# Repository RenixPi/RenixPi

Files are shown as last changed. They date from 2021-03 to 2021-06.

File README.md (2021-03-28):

# Getting Started

> TODO
> Create an `.img` that be used to create SD Card with the [RaspberryPi Imager](https://www.raspberrypi.org/software/).

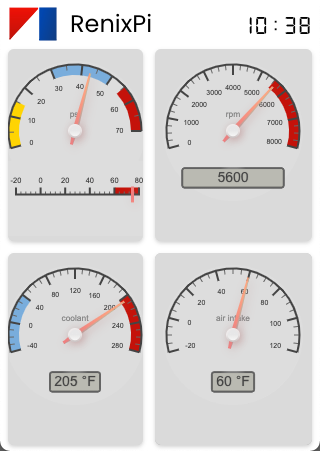
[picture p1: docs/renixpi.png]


# Renix History

A declining economy coupled with the soaring energy prices of the 1970s, American Motor Corporation (AMC)
struggled in 1980. Their vehicle lineup wasn't able to keep pace with General Motors, Chrysler and Ford. And
Japanese imports were now being produced domestically in highly efficient assembly plants.

Not able to secure loans from traditional sources, Renault provided funding to keep AMC going and eventually
acquired more than 50% of the company by 1982. The company turned focus to its Jeep brand with down-sized versions
of other models; the Wagoneer and Cherokee -- launched in 1983 -- created an entirely new sports utility vehicle
class of cars.  

Initially, these vehicles had a 2.5L inline-4 AMC engine or a GM-made 2.8L V6, both naturally aspirated with
a carburetor. In 1987, Jeep and Renault designed an inline, 6-cylinder engine. Drawing from another Renault joint
venture with aerospace company Bendix, they outfitted both the 2.5L and 4L engine with an electronic fuel injection
system. Renault-Bendix was shortened to Renix.

When Chysler acquired Jeep in 1991, they replaced the engine management system with their own ECU. However, 
during just those four years of production, Jeep sold a combined *1.1 million* Wagoneers, 
Cherokees (XJ) and Comanches (MJ) with the Renix system.

## Engine management protocols

While the On Board Diagnostic (OBD) protocol was established by [SAE in 1979](https://www.sae.org/standards/content/j1979_201202/),
it wasn't until 1994, when California emissions regulations mandated it be included on all vehicles, that it became the
industry standard now known as OBD-II.

Between 1979 and 1994, most companies used some portion of the OBD standard. Renix did not, charting their
own path with a proprietary format.

## Reverse engineering of the Renix protocol

While some commercially available diagnostic tools were made for mechanics, the protocol was never published. In 2012, a video by
[Phil Andrews of the RenixPower forum](https://www.youtube.com/watch?v=AUqQrLLVdZ8) demonstrated his hard work in decoding the protocol.

Following that, [Nick Grisley of NickInTimeDesign](http://nickintimedesign.com) started developing the
[Renix Engine Monitor](https://nickintimedesign.com/product/renix-engine-monitor-ii/) in 2016 and has been generous to
share the source code as an open source project. There are several videos on his website that show the extensive sleuthing
that was needed to arrive in his latest iteration. I've purchased one and I've been very impressed, it works great!

This project is an extension of both Phil and Nick's *tremendous* efforts and would not have been possible without them.

### Sources

- [Automotive History Preservation Society](http://wildaboutcarsonline.com/cgi-bin/pub9990262549620.cgi?itemid=9990287331811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)
- [Renix Wikipedia](https://en.wikipedia.org/wiki/Renix)
- [OBD Wikipedia](https://en.wikipedia.org/wiki/On-board_diagnostics)
- [Origins by NickInTimeDesign](https://nickintimedesign.com/where-it-all-began/)

# Electronics

The ECU serial data connection is a fairly standard interface (open-collector to ground)
which isn't dependent on the voltage of the connected electronics. Parts that are needed

- raspberry pi ~$35
- display (minimum 480x320 resolution) ~$20
- transistor (eg 2N2309) < $1
- resistors (eg 4 x 1K ohm) < $1
- power supply (see notes)  ~$4
- diagnostic connector ~$5
- wire

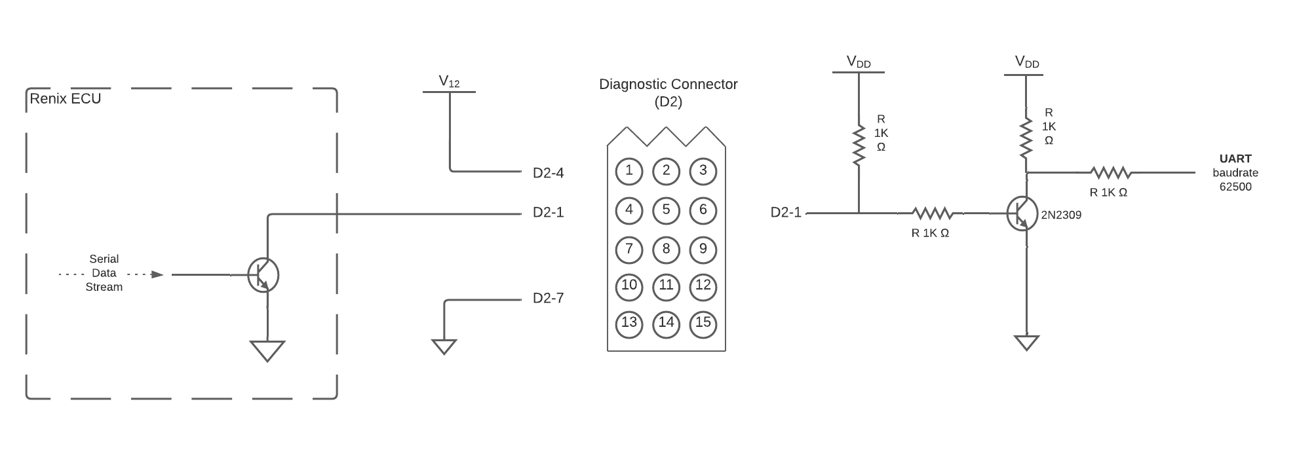
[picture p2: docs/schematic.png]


## ECU Diagnostic Connector

The diagnostic connector in the vehicle is a standard 15-pin Molex connector; receptacle with female 0.093" pins. To connect, you'll
need the [plug](<docs/molex-plug.jpeg>) (top right) with [male pins](<docs/molex-pin.jpeg>) (bottom left).

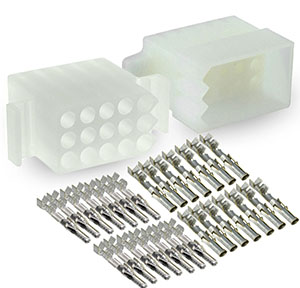
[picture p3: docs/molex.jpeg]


## Power supply

The RaspberryPi requires a 5V supply but its input pins are limited to 3.3V so the UART connection
needs this lower Vdd pull-up voltage.

**Option 1** Use Vdd from the power pins of the Raspberry Pi and level shift
the UART using a zener diode (1N4619) and a 100 ohm resistor.

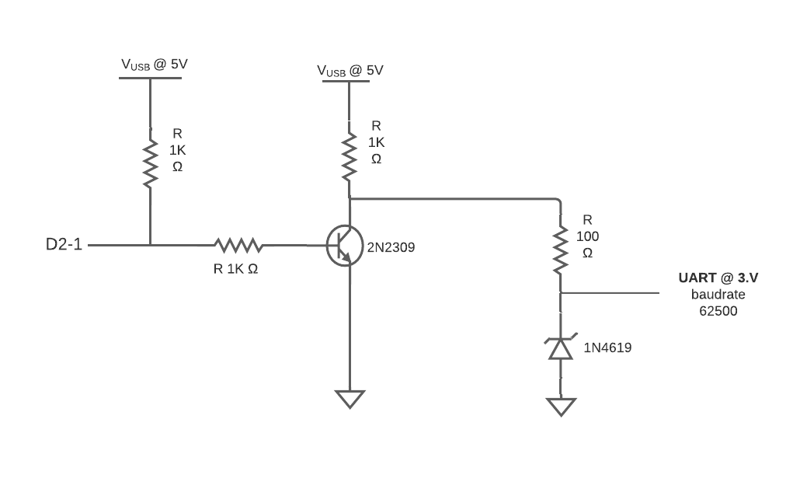
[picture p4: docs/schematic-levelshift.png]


**Option 2** Amazon or Ebay (among others) have dc-to-dc step down converters based on the
LM2596 and cost about $12 for a pack of 6. One should be adjusted to 5V and the other
to 3.3V.

**Option 3** The RaspberryPi can be powered by a USB charging port (5V) from a cigarette lighter
adapter supplying at least 2A. While the 3.3V regulator on the RaspberryPi isn't easily accessible
through the GPIO header, it might be possible to get the right voltage by configuring an output pin
and setting it to '1'. The max current is only 17 mA but, in theory, that should be enough
to activate the 2N2309 transistor.

# Software

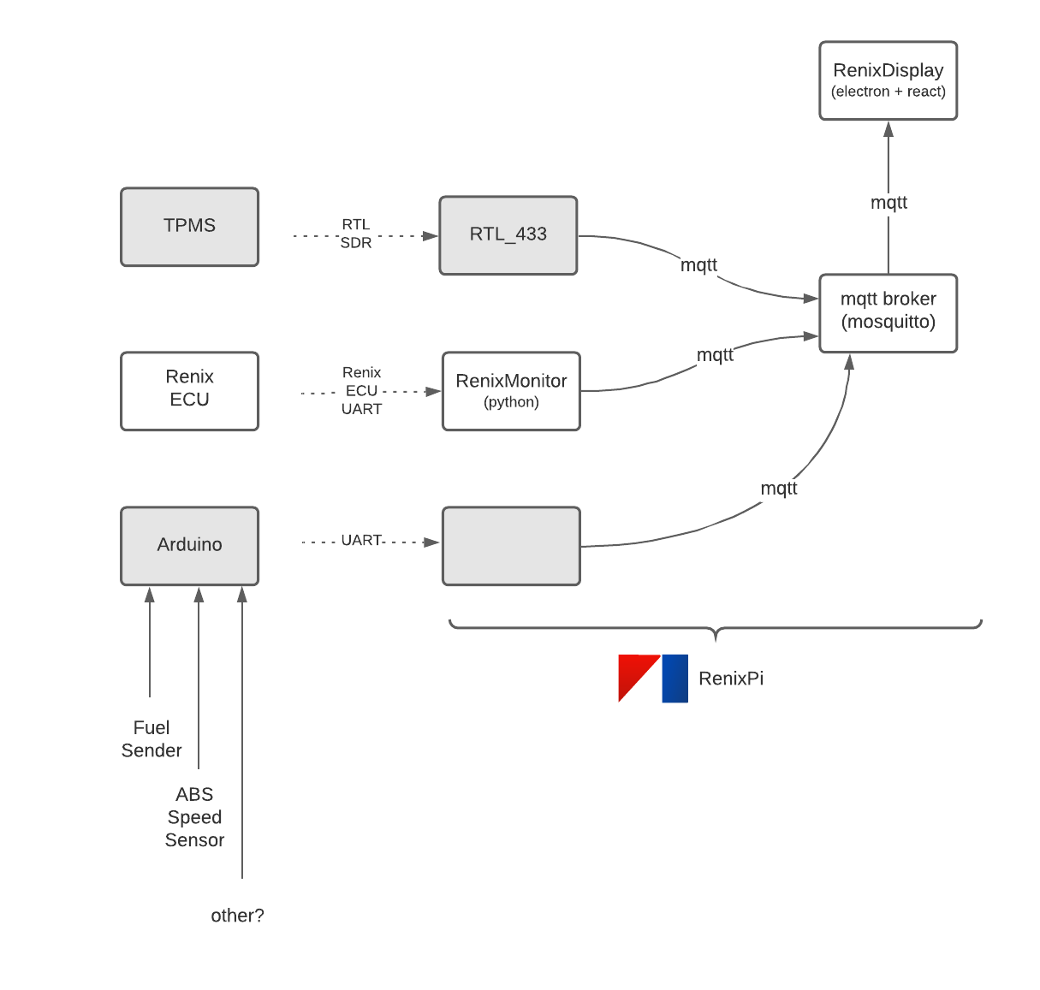
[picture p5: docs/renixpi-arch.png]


## Install

Assumes that you are using a RaspberryPI Desktop OS image that already has `git` and `python3` installed. From either a 
terminal window or command prompt via ssh:

1. clone [RenixPi](https://github.com/RenixPi/RenixPi.git)
1. install `ansible` with `pip3 install ansible`
1. `cd RenixPi/config` and run `ansible-playbook renix.yml` which will clone 
   [RenixMonitor](https://github.com/RenixPi/RenixMonitor.git) and [RenixDisplay](https://github.com/RenixPi/RenixDisplay.git)
   along with installing their dependencies.
1. `cd RenixMonitor`
1. `python3 main.py --baudrate 62500 --interface /dev/ttyAMA1 &`
1. `cd ../RenixDisplay`
1. `npm run prod` (or `npm run build` followed by `npm run launch`)

Note: on the RaspberryPi 4, there are more than two uarts so you may need to adjust the interface depending on your configuration. 

## RenixMonitor

Decodes serial data stream from Renix ECU. Python. Supports both python3 and micropython.

https://github.com/RenixPi/RenixMonitor

## RenixDisplay

Electron app built with React, Redux and RxJS. Javascript. Displays information coming from RenixMonitor and any other
MQTT source.

https://github.com/RenixPi/RenixDisplay

# Configuration

### Ethernet

No configuration necessary.

### Wireless

In the base directory of the SD card, rename `wpa_supplicant.txt` to `wpa_supplicant.conf` and change the SSID and wifi password.

### SSH

> TODO

`ssh pi@renix.local`

### Display

- size
- orientation

> TODO

### Engine Type

Currently, only 4L M/T is supported.

*Like to see this implemented? Request with a github issue!*

> TODO

#### UART

> TODO

#### TPMS (optional)

> TODO

#### Other (optional)

> TODO

# References

```
>>> # create virtual serial port
>>> socat -d -d pty,raw,echo=0 pty,raw,echo=0
```

```
>>> # run ansible to set up user and ssh config
>>> ansible-playbook -i hosts raspi.yml
```

```
>>> # run ansible to set up renix dependencies
>>> ansible-playbook -i hosts renix.yml
```

```
>>> # run electron app on raspberry pi
>>> export DISPLAY=:0
>>> npm run prod
```

```
>> # rotate screen
>> DISPLAY=:0 xrandr --output HDMI-1 --rotate left
```

```
>> # turn on display that's sleeping
>> DISPLAY=:0 xset s on s 60
>> DISPLAY=:0 xset s activate

```

references: 
https://reelyactive.github.io/diy/pi-kiosk/

## Renix Protocol

The UART-based serial protocol used by the Renix

| Byte # | 4L value | 2.5L value |
| --- | --- | --- |
| \-2 | 0xFF | 0xFF |
| \-1 | 0x00 | 0x00 |
| 0 | software version | |
| 1 | prom | |
| 2 | status | |
| 3 | mass absolute pressure | |
| 4 | coolant temp sensor | |
| 5 | intake air temp | |
| 6 | battery voltage | |
| 7 | O2 sensor | |
| 8 | spark timing (lower byte) | |
| 9 | spark timing (upper byte) | |
| 10 | injector short | |
| 11 | injector open | |
| 12 | throttle position sensor  | |
| 13 | spark advance | |
| 14 | idle air control | |
| 15 | | |
| 16 | atmospheric pressure | |
| 17 | | |
| 18 | | |
| 19 | injector pulse | |
| 20 | | |
| 21 | | |
| 22 | | |
| 23 | | |
| 24 | short fuel | |
| 25 | | |
| 26 | long fuel | |
| 27 | knock | |
| 28 | | |
| 29 | | |
| 30 | error codes | |

## A/T Transmission Protocol

*Like to see this implemented? Request with a github issue!*

## ABS Protocol

*Like to see this implemented? Request with a github issue!*

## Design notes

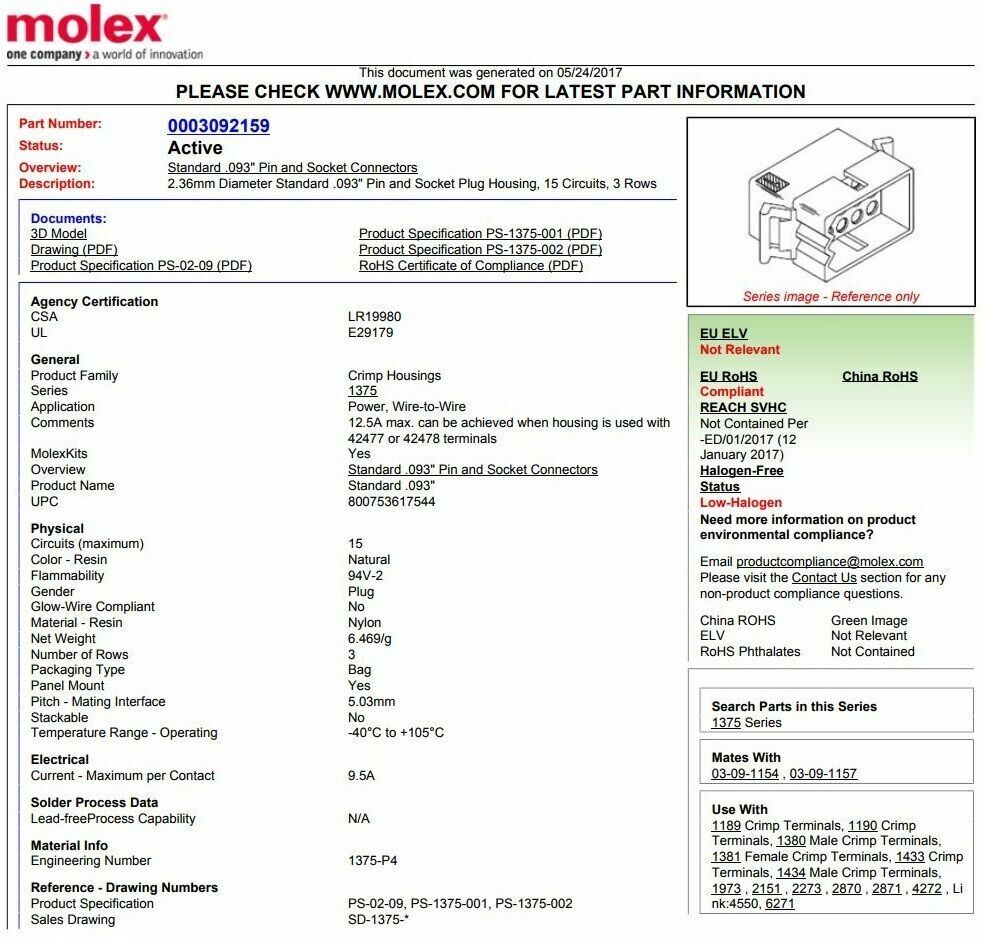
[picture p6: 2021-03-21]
docs/molex-plug.jpeg

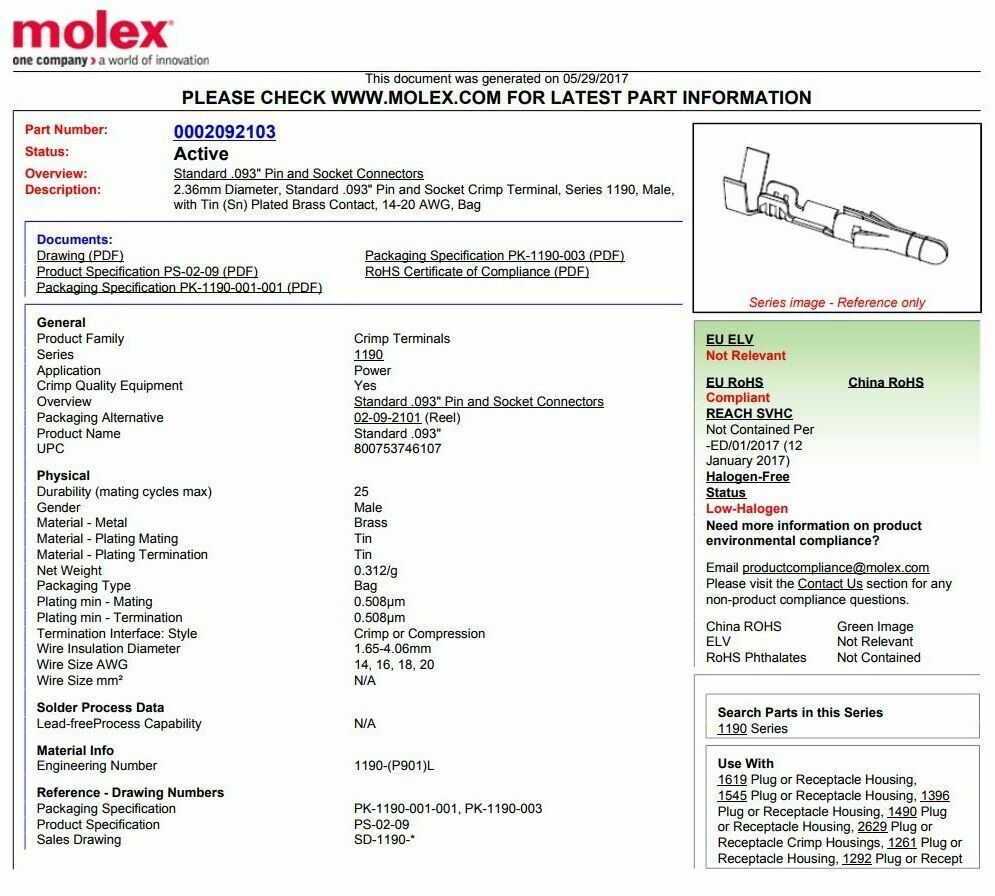
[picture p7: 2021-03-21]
docs/molex-pin.jpeg

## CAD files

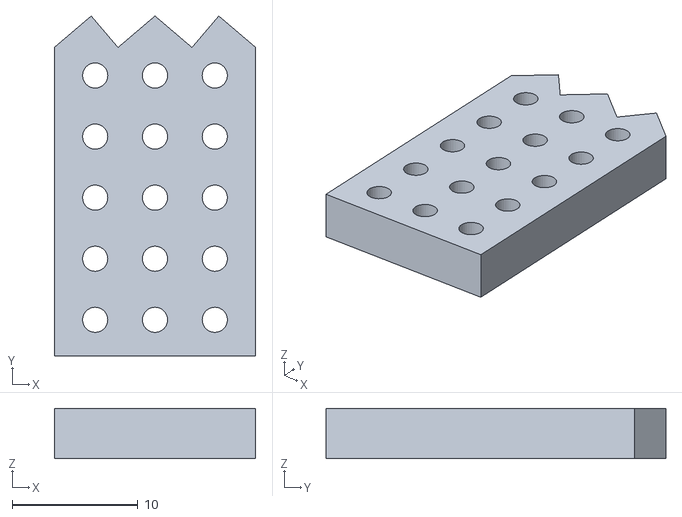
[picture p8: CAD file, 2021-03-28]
connector/renix-plug.stl
16.0 x 27.0 x 4.00

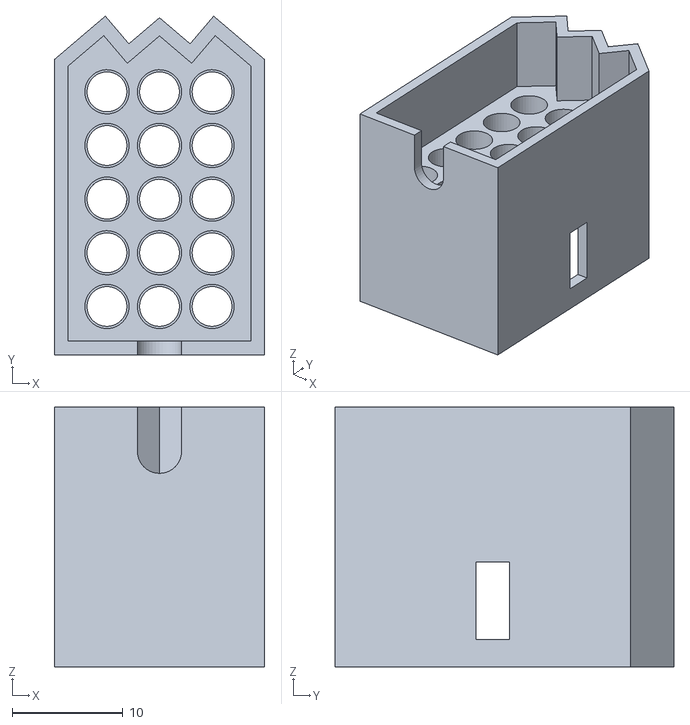
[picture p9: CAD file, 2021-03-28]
connector/renix-plug-cap.stl
19.0 x 30.6 x 23.5

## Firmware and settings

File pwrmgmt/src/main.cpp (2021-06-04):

#include <PinChangeInt.h>
#define DEBUG

#include <PiDevice.h>
#include <states.h>
#include <transitions.h>
#include <triggers.h>
#include <SleepyPi2.h>

unsigned long TIME__WAIT_BEFORE_SHUTDOWN = (unsigned long)2*60*1000;
unsigned long TIME__WAIT_BEFORE_POWER_OFF = (unsigned long)30*1000;

// Adafruit_INA260 ina260 = Adafruit_INA260();

void initial__enter() {
  #ifdef DEBUG
  Serial.println("initial state");
  #endif
  //pis should start off
  RenixPi.disablePower();
  OpenDshPi.disablePower();
}
State initial(&initial__enter, NULL, NULL);
Fsm powermgr(&initial);

void pi_off__enter() {
  Serial.println("pis are off");

  //should already be off, just in case
  RenixPi.disablePower();
  OpenDshPi.disablePower();
}

void pi_off__actions() {
  if(digitalRead(IGNITION_PIN) > 0) {
    powermgr.trigger(TRIGGER__IGN_ON);
  } else {
    powermgr.trigger(TRIGGER__IGN_OFF);
  }
}

void sleep__enter() {
  #ifdef DEBUG
  Serial.println("taking a nap");
  // Serial.println(SleepyPi.supplyVoltage());
  // Serial.println(SleepyPi.rpiCurrent());
  // Serial.println(RenixPi.getCurrentDraw());
  // Serial.println(OpenDshPi.getCurrentDraw());
  #endif
  delay(500);
  LowPower.powerDown(SLEEP_FOREVER, ADC_OFF, BOD_OFF);
}

void pi_on__enter() {
    // turn pi power on
    RenixPi.enablePower();
    OpenDshPi.enablePower();
    #ifdef DEBUG
    Serial.println("turning on");
    #endif
}

void hold__enter() {
    #ifdef DEBUG
    Serial.println("entering hold ");
    Serial.print(RenixPi.getCurrentDraw());
    Serial.print("\t\t");
    Serial.println(OpenDshPi.getCurrentDraw());
    #endif
}

void start_shutdown__enter() {
    //begin shutdown sequence
    RenixPi.shutdown();
    OpenDshPi.shutdown();
    #ifdef DEBUG
    Serial.println("starting shutdown sequence");
    #endif
}

void start_shutdown__actions() {
  if(!RenixPi.isRunning() && !OpenDshPi.isRunning()) {
    #ifdef DEBUG
    Serial.println("both pis are not running");
    #endif
    powermgr.trigger(TRIGGER__NOT_RUNNING);
  }
}

void not_running__enter() {
  #ifdef DEBUG
  Serial.println("not running");
  #endif
}

void not_running__actions() {
  #ifdef DEBUG
    Serial.println("not running");
    Serial.print(RenixPi.getCurrentDraw());
    Serial.print("\t\t");
    Serial.println(OpenDshPi.getCurrentDraw());
    delay(500);
  #endif

  if(!RenixPi.isPoweredOn() && !OpenDshPi.isPoweredOn()) {
    #ifdef DEBUG
    Serial.println("both pis are powered off");
    #endif
    powermgr.trigger(TRIGGER__NOT_POWERED);
  }
}

void not_powered__enter() {
  #ifdef DEBUG
  Serial.println("not powered, turning power off");
  #endif
  RenixPi.disablePower();
  OpenDshPi.disablePower();
}

void not_responsive() {
  #ifdef DEBUG
  Serial.println("not responsive, turn off");
  #endif
}

void on_wakeup() {
    // when sleepypi wakes from its nap
    #ifdef DEBUG
    Serial.println("waking up");
    #endif
}

State pi_off(&pi_off__enter, &pi_off__actions, NULL);
State sleep(&sleep__enter, NULL, NULL);
State pi_on(&pi_on__enter, NULL, NULL);
State hold(&hold__enter, NULL, NULL);
State start_shutdown(&start_shutdown__enter, &start_shutdown__actions, NULL);
State not_running(&not_running__enter, &not_running__actions, NULL);
State not_powered(&not_powered__enter, NULL, NULL);



// initial configuration
void setup()
{
  Serial.begin(9600);
  Serial.println("starting...");

  // use the ignition power to wake up the sleepypi
  pinMode(IGNITION_PIN, INPUT);
  PCintPort::attachInterrupt(IGNITION_PIN, &on_wakeup, RISING);

  //state: initial
  powermgr.add_timed_transition(&initial, &pi_off, 1, NULL);

  //state: pi_off
  powermgr.add_transition(&pi_off, &sleep, TRIGGER__IGN_OFF, NULL);
  powermgr.add_transition(&pi_off, &pi_on, TRIGGER__IGN_ON, NULL);

  //state: sleep
  powermgr.add_transition(&sleep, &pi_on, TRIGGER__IGN_ON, NULL);

  //state: pi_on
  powermgr.add_transition(&pi_on, &hold, TRIGGER__IGN_OFF, NULL);

  //state: hold
  powermgr.add_timed_transition(&hold, &start_shutdown, TIME__WAIT_BEFORE_SHUTDOWN, NULL);
  powermgr.add_transition(&hold, &pi_on, TRIGGER__IGN_ON, NULL);
  
  //state: start shutdown
  powermgr.add_transition(&start_shutdown, &not_running, TRIGGER__NOT_RUNNING, NULL);
  powermgr.add_timed_transition(&start_shutdown, &pi_off, TIME__WAIT_BEFORE_POWER_OFF, &not_responsive);
  
  //state: not running
  powermgr.add_transition(&not_running, &not_powered, TRIGGER__NOT_POWERED, NULL);
  powermgr.add_timed_transition(&not_running, &pi_off, TIME__WAIT_BEFORE_POWER_OFF, &not_responsive);

  //state: not powered
  powermgr.add_timed_transition(&not_powered, &pi_off, 500, NULL);

}

void loop()
{

  // check timed transitions, execute any in-state callbacks
  powermgr.run_machine();

  // if ignition is on, send trigger
  if(digitalRead(IGNITION_PIN) > 0) {
    powermgr.trigger(TRIGGER__IGN_ON);
  } else {
    powermgr.trigger(TRIGGER__IGN_OFF);
  }

  delay(1000);
}

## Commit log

2021-03-19 creating ansible scripts for initializing raspberry pi
2021-03-21 adding schematics
2021-03-22 more updates to raspberry pi setup scripts
2021-03-28 updates to the readme. additional steps for renix pi configurationg. added molex connector.
    [renix-plug-cap.stl, renix-plug.stl]
2021-04-06 adding tire pressure measurements. enabling prometheus logging
2021-04-26 renix power management class header and initial functions
2021-05-01 adding fsm and thread library
2021-05-01 states and transitions for power management
2021-05-02 basic fsm for powermanagement for the renix pi
2021-05-02 created abstraction for a device so that there can be two... one for renix and one for opendsh
2021-05-02 created fsm subclass so both devices have their own shutdown sequence
2021-05-02 finishing fsm specifically for pi. adding 'name' to pi device for print outs
2021-05-02 removing renix power singleton since PiDevice and PiFSM replace
    [main.cpp]
2021-05-03 added a startup state. however, because both renix and opendsh tell the controller to go to sleep. there is a bug
    [main.cpp]
2021-05-03 implementing new combined power management fsm
2021-05-03 verifying powered off monitor. on non responsive override
2021-05-04 separate out current draw logic and include transformation into mAs
2021-05-09 adding in ina260 current monitor
2021-05-09 incorporating ina260 current monitoring. fixing pins to match soldering.
    [main.cpp]
2021-05-25 upload command from arduino ide
2021-08-18 building the state machine for powering
